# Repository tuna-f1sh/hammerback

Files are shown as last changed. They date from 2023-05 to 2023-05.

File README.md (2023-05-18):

# Hammerback - Battery Backpack for Hammerhead Karoo 2

A quick prototype to expand the battery of the Hammerhead Karoo 2 by attaching a larger battery between the device and handlebar mount.

It is essentially a [Adafruit Powerboost 1000C](https://www.adafruit.com/product/2465) in a layout with vertical USB-C to the Karoo 2 and a side USB-C for charging. The _backpack_ contains a LiPo (that connects to the PCB), Karoo 2 style mount and quarter turn at the base for attaching to bike. It is secured by taking the place of the USB-C cover plate with extended T8 screws.

## Photos

**Not my best soldering!**

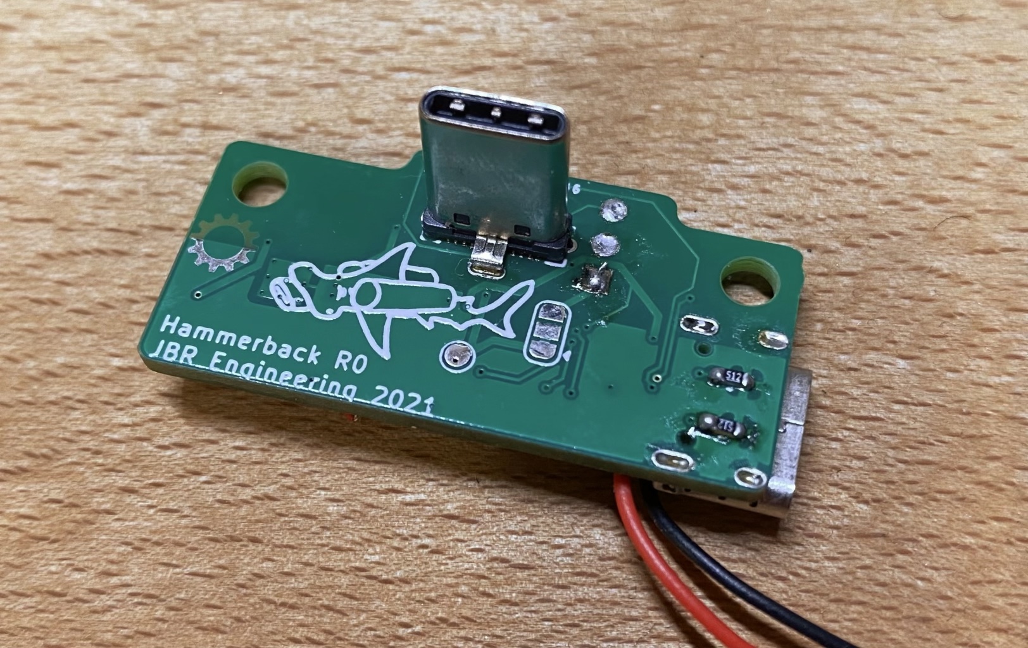
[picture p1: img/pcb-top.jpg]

**Made some nice silkscreen art 😁**
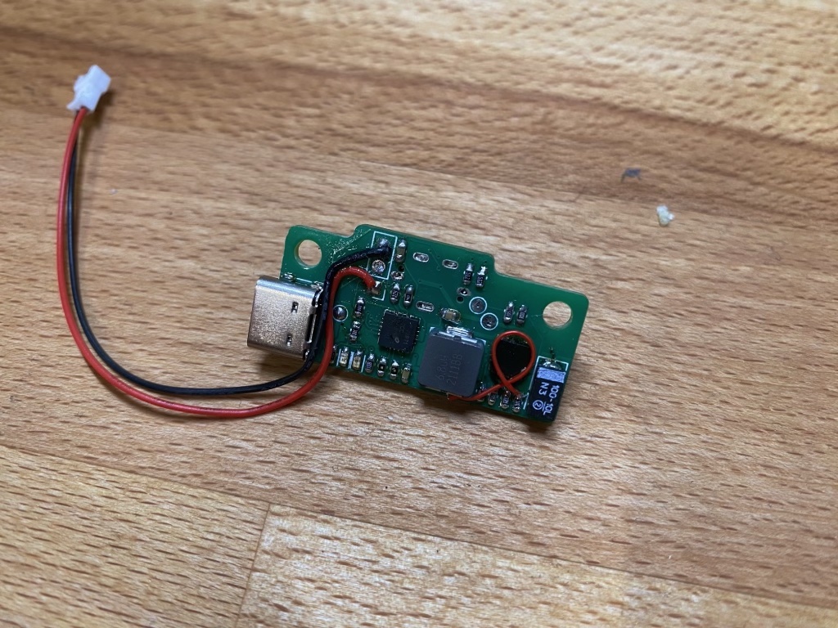
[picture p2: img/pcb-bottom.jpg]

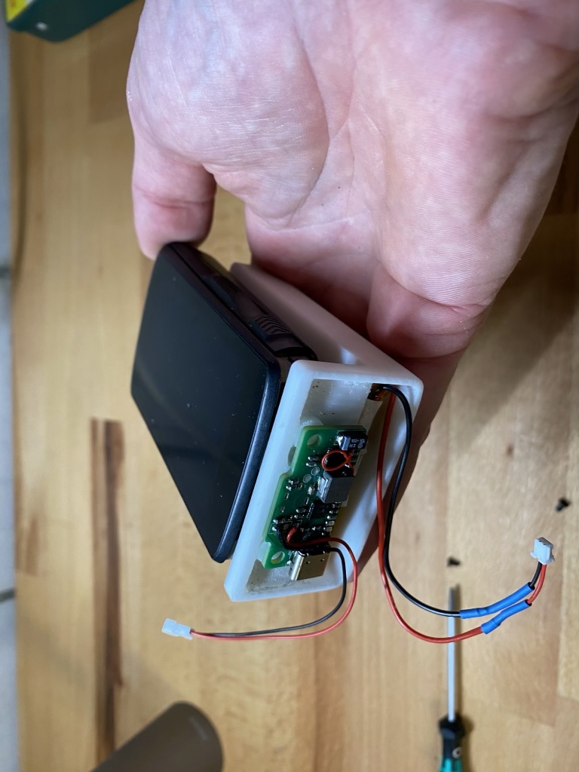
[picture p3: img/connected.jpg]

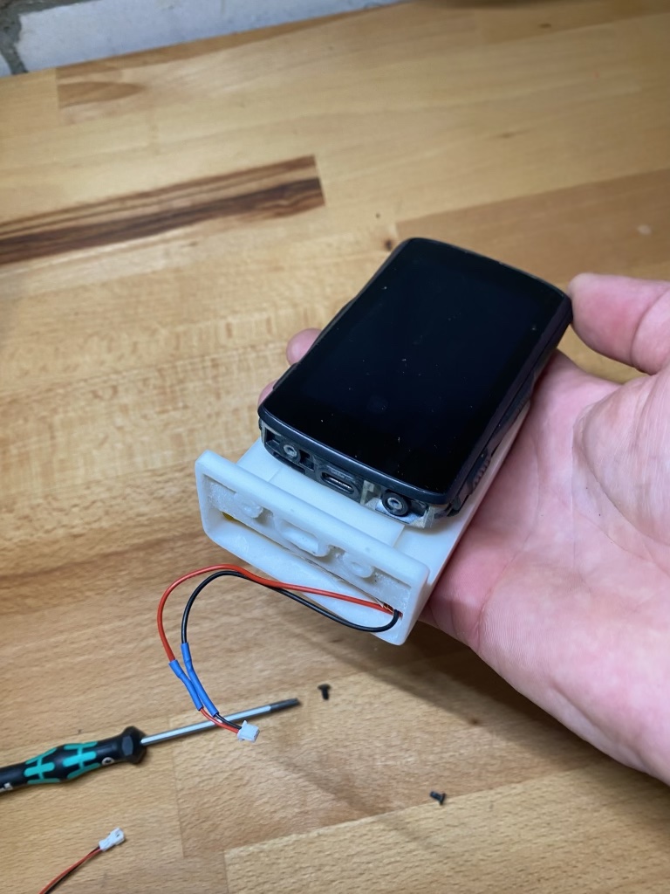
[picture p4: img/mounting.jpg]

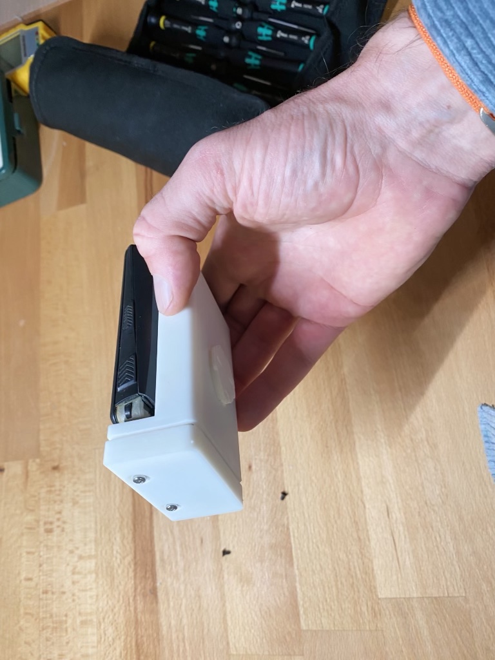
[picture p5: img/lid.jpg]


## Project State

I put this together quickly as an idea. Whilst it worked in principle, it could do with some refining. I also have other ideas that could be included:

* Illumination - use the LiPo as a supply for a small front light if a transparent backpack is used.
* Switch for turning on/off. Currently it will supply the Karoo until the LiPo is empty or one must to remove it.
* The design could also be simplified to simply be the vertical USB-C to Karoo, with a header for a 5 V source - this could be used with an existing battery pack rather so using that BMS/charging rather than on-board.

# Mechanicals

[Fusion 360 design](https://a360.co/3pR5RNK)

# Disclaimer

It should be obvious but this is supplied without warranty and to be used at user's discretion. Always be careful when using LiPo cells. I cannot guarantee the working state of this.

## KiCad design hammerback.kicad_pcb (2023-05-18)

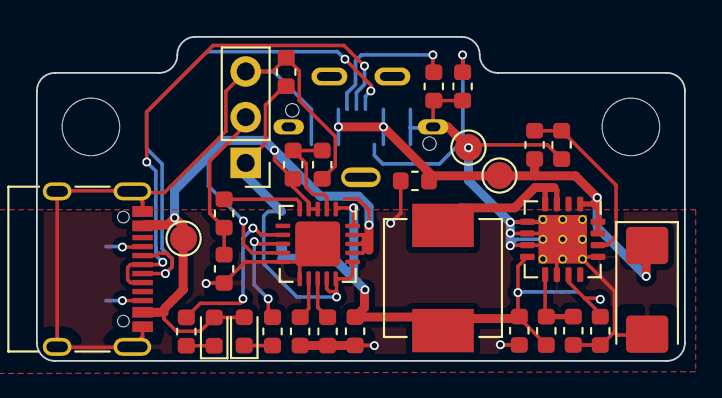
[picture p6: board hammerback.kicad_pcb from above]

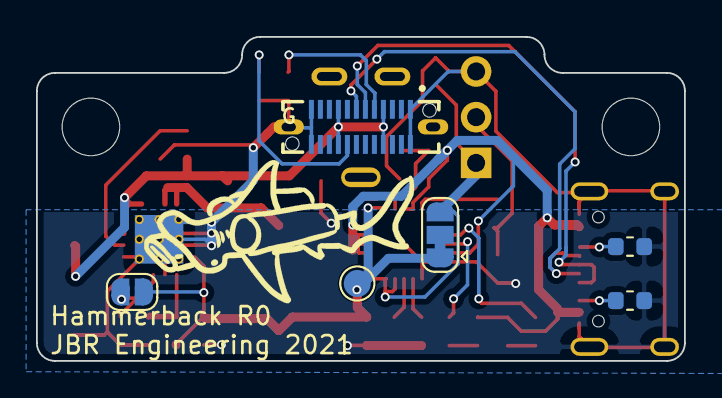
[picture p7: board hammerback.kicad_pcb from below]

Board: 2 copper layers, 36.0 x 18.0 mm, 38 parts (6 on the bottom side), 24 nets.

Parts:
C1, C2: 10u; C_0603_1608Metric
C3: 100n; C_0603_1608Metric
C4: 2.2u; C_0603_1608Metric
C5: 100u; CP_EIA-6032-20_AVX-F
D1: CHARGE; LED_0603_1608Metric
D2: DONE; LED_0603_1608Metric
H1, H2: MountingHole; MountingHole_3.2mm_M3_ISO14580
J2: LiPo; PinHeader_1x03_P2.54mm_Vertical
JP1: SolderJumper_3_Bridged12; SolderJumper-3_P1.3mm_Bridged12_RoundedPad1.0x1.5mm
JP2: SolderJumper_2_Open; SolderJumper-2_P1.3mm_Open_RoundedPad1.0x1.5mm
L1: 6.8uH; L_Vishay_IHLP-2525
P1: USB_C_Plug_USB2.0; GCT_USB4151-GF-C_REVA
R1, R2: 1k; R_0603_1608Metric
R3: 270k; R_0603_1608Metric
R4: 100k; R_0603_1608Metric
R5, R7, R10: 1k54; R_0603_1608Metric
R6: 69k8; R_0603_1608Metric
R8, R9, R14, R15: 5k1; R_0603_1608Metric
R11: 1.87M; R_0603_1608Metric
R12: 340k; R_0603_1608Metric
R13: 10k; R_0603_1608Metric
R16: 2M; R_0603_1608Metric
R17: 200k; R_0603_1608Metric
TP1, TP2, TP3, TP4: TestPoint; TestPoint_Pad_D1.5mm
U1: MCP73871; QFN-20-1EP_4x4mm_P0.5mm_EP2.5x2.5mm
U2: TPS61090; Texas_S-PVQFN-N16_EP2.7x2.7mm_ThermalVias
ee1: USB_C_Receptacle_USB2.0; USB_C_Receptacle_XKB_U262-16XN-4BVC11

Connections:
+5V: C4.1, C5.1, P1.A4, P1.A9, P1.B4, P1.B9, R16.1, TP4.1, U2.1, U2.15, U2.16
/BOOST: JP2.1, R13.1, U2.11
/NTC: J2.2, R5.2, R6.1
/STAT1: R7.2, U1.8
/STAT2: R10.2, U1.7
/USB_N: P1.A7, ee1.A7, ee1.B7
/USB_P: P1.A6, ee1.A6, ee1.B6
GND: C1.2, C2.2, C3.2, C4.2, C5.2, J2.3, P1.A1, P1.A12, P1.B1, P1.B12, P1.S1, R1.2, R2.2, R4.2, R6.2, R8.1, R9.1, R12.2, R13.2, R14.1, R15.1, R17.2, TP1.1, U1.10, U1.11, U1.21, U2.5, U2.6, U2.7, U2.10, U2.13, U2.17, ee1.A1, ee1.A12, ee1.B1, ee1.B12, ee1.S1
unnamed: C1.1, J2.1, JP1.3, U1.14, U1.15, U1.16
unnamed: C2.1, C3.1, JP1.1, JP2.2, L1.1, R11.1, TP3.1, U1.1, U1.20, U2.8
unnamed: D1.1, R7.1
unnamed: D2.1, R10.1
unnamed: L1.2, U2.3, U2.4
unnamed: P1.A5, R14.2
unnamed: P1.B5, R15.2
unnamed: R1.1, U1.13
unnamed: R2.1, U1.12
unnamed: R3.2, R4.1, U1.2
unnamed: R5.1, U1.5
unnamed: R8.2, ee1.B5
unnamed: R9.2, ee1.A5
unnamed: R11.2, R12.1, U2.9
unnamed: R16.2, R17.1, U2.14
VBUS: D1.2, D2.2, R3.1, TP2.1, U1.3, U1.4, U1.9, U1.17, U1.18, U1.19, ee1.A4, ee1.A9, ee1.B4, ee1.B9

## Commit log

2021-07-15 breakout for vertical plug
    [hammerback.kicad_pcb, hammerback.sch]
2021-07-29 fix hole size in pad
    [hammerback.kicad_pcb, hammerback.sch]
2022-03-30 pcb updates
    [hammerback.kicad_pcb, hammerback.sch]
2023-05-18 update for kicad 7
    [hammerback.kicad_pcb, hammerback.kicad_sch, hammerback.sch]
